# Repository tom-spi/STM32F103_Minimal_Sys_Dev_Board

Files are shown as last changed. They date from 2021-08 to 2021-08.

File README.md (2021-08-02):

# STM32F103_Minimal_Sys_Dev_Board

A minimal system STM32F103 based development board. All Major communication interfaces broken out. USB 2.0 device support. Complete with 3.3V regulator & 16MHz external crystal.
All I/O pins broken out onto headers & an SWD Header for programming. 
Boards manufactured and assembled by JLCPCB.

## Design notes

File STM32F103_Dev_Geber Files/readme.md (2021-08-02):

Gerber & drill files used for PCB manufacture.

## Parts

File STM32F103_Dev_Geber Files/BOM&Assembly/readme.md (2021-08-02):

BOM & position file for assembly. (In JLCPCB format)

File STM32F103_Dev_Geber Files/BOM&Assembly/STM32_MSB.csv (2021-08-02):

Comment | Designator | Footprint | LCSC
4u7 | C1,C3 | Capacitor_SMD:C_0603_1608Metric | C19666
1u | C2 | Capacitor_SMD:C_0603_1608Metric | C15849
100n | C4,C5,C6,C7 | Capacitor_SMD:C_0603_1608Metric | C14663
12p | C8,C9 | Capacitor_SMD:C_0603_1608Metric | C38523
3v3 | D1 | Capacitor_SMD:C_0805_2012Metric | C2297
USB_B_Micro | J1 | Connector_USB:USB_Mini-B_Wuerth_65100516121_Horizontal | C91144
I/O1 | J2 | Connector_PinHeader_2.54mm:PinHeader_2x07_P2.54mm_Vertical
I/O2 | J3 | Connector_PinHeader_2.54mm:PinHeader_2x07_P2.54mm_Vertical
CAN | J4 | Connector_PinHeader_2.54mm:PinHeader_1x02_P2.54mm_Vertical
I2C | J5 | Connector_PinHeader_2.54mm:PinHeader_1x02_P2.54mm_Vertical
USART | J6 | Connector_PinHeader_2.54mm:PinHeader_1x02_P2.54mm_Vertical
SWD | J7 | Connector_PinHeader_2.54mm:PinHeader_2x05_P2.54mm_Vertical
SPI | J8 | Connector_PinHeader_2.54mm:PinHeader_1x03_P2.54mm_Vertical
Jumper_NC_Small | JP1 | Connector_PinHeader_2.54mm:PinHeader_1x02_P2.54mm_Vertical
SolderJumper_2_Open | JP2 | Jumper:SolderJumper-2_P1.3mm_Open_RoundedPad1.0x1.5mm
1.5k | R1,R2 | Resistor_SMD:R_0603_1608Metric | C22843
10K | R3 | Resistor_SMD:R_0603_1608Metric | C25804
47 | R4 | Resistor_SMD:R_0603_1608Metric | C23182
4.7k | R5,R6 | Resistor_SMD:R_0603_1608Metric | C23162
MCP1825S | U1 | Package_TO_SOT_SMD:SOT-223-3_TabPin2
STM32F103C8Tx | U2 | Package_QFP:LQFP-48_7x7mm_P0.5mm | C8734
16MHz | Y1 | Crystal:Crystal_SMD_3225-4Pin_3.2x2.5mm | C13738

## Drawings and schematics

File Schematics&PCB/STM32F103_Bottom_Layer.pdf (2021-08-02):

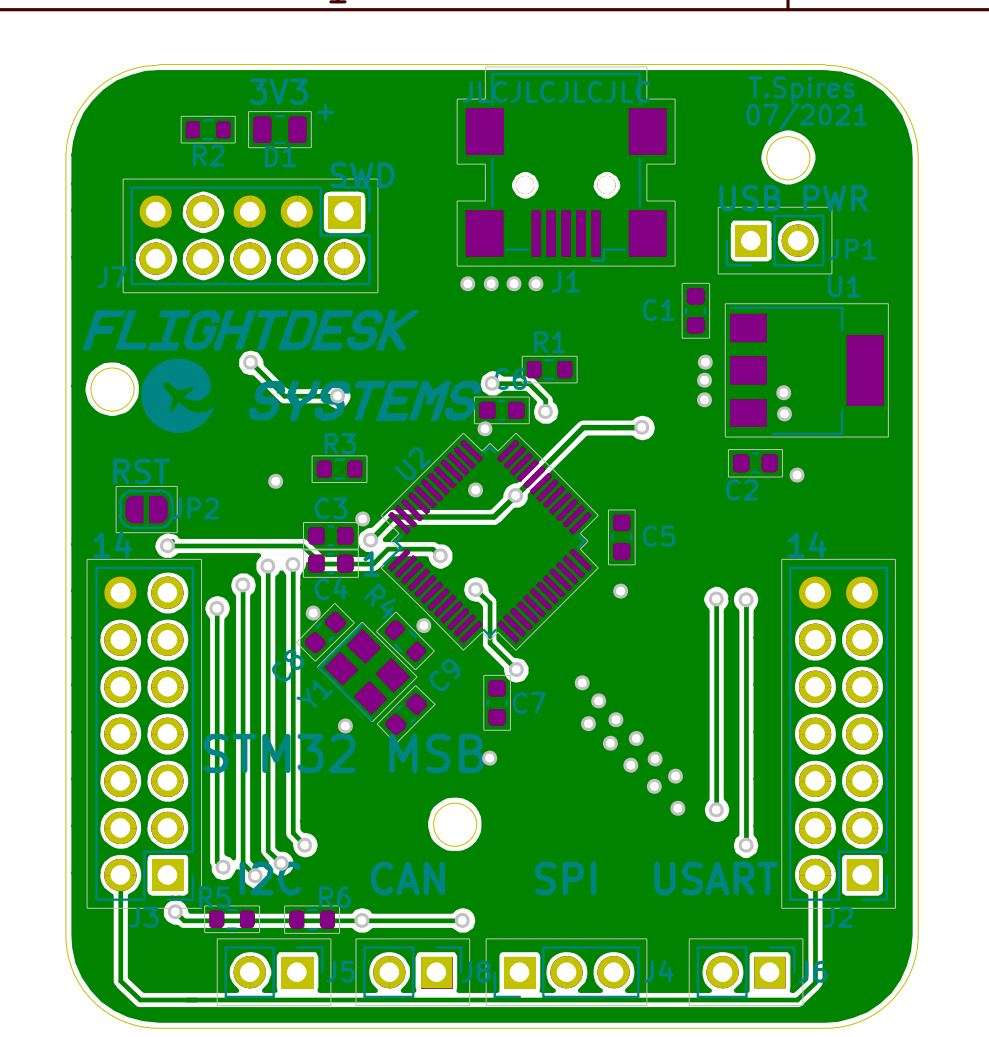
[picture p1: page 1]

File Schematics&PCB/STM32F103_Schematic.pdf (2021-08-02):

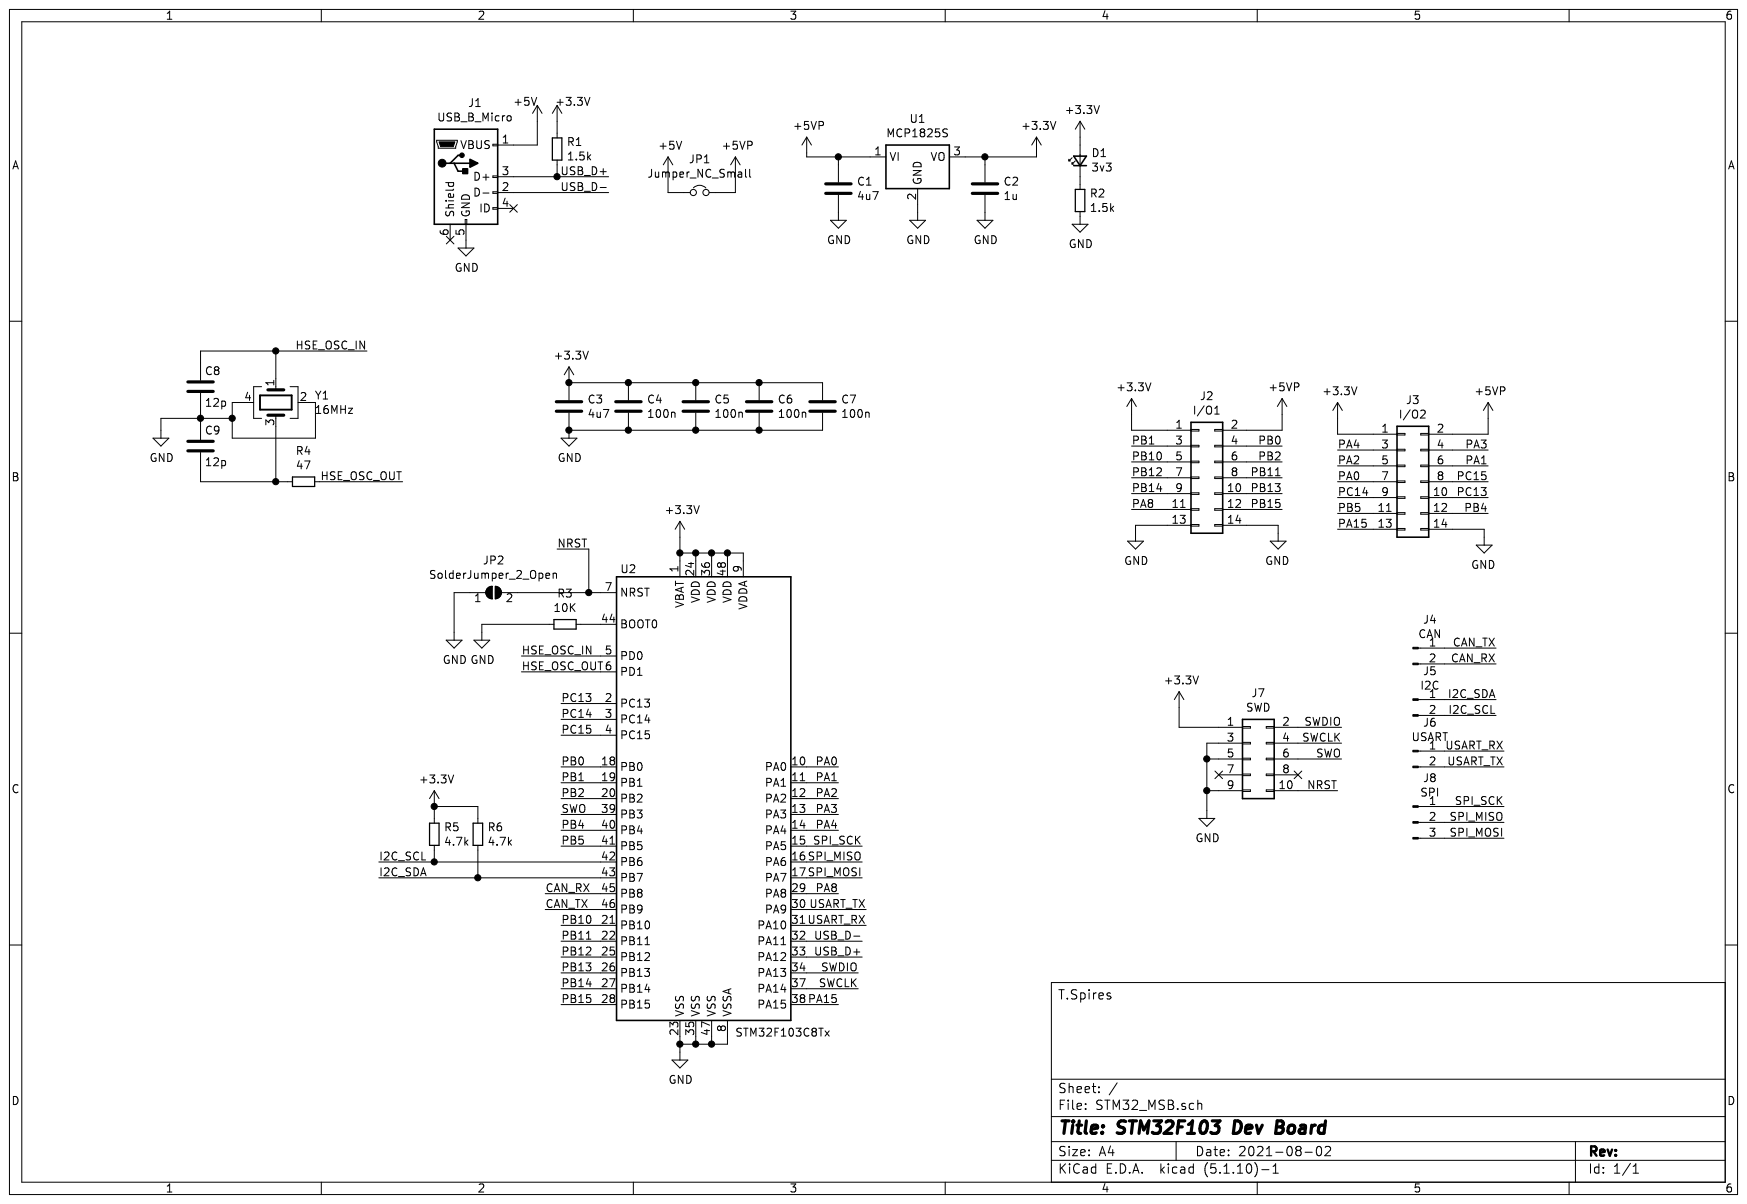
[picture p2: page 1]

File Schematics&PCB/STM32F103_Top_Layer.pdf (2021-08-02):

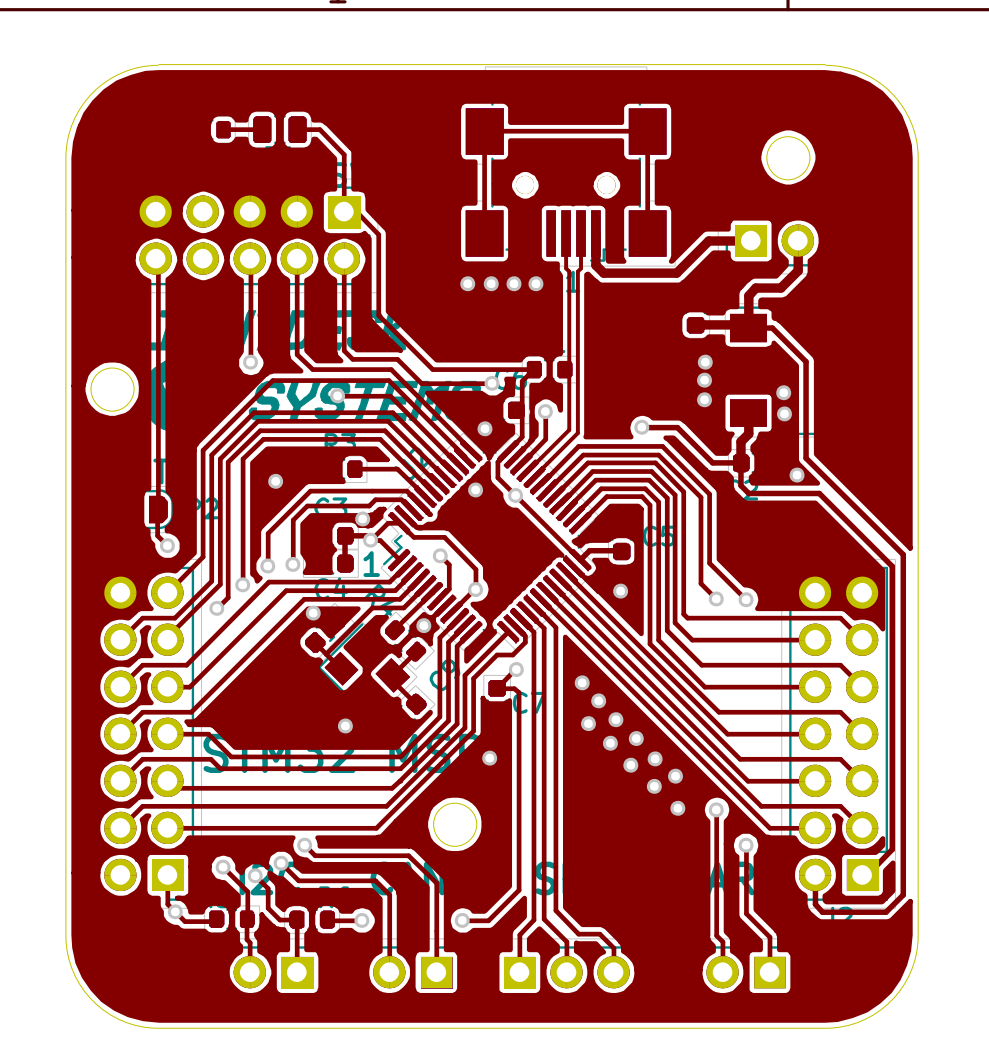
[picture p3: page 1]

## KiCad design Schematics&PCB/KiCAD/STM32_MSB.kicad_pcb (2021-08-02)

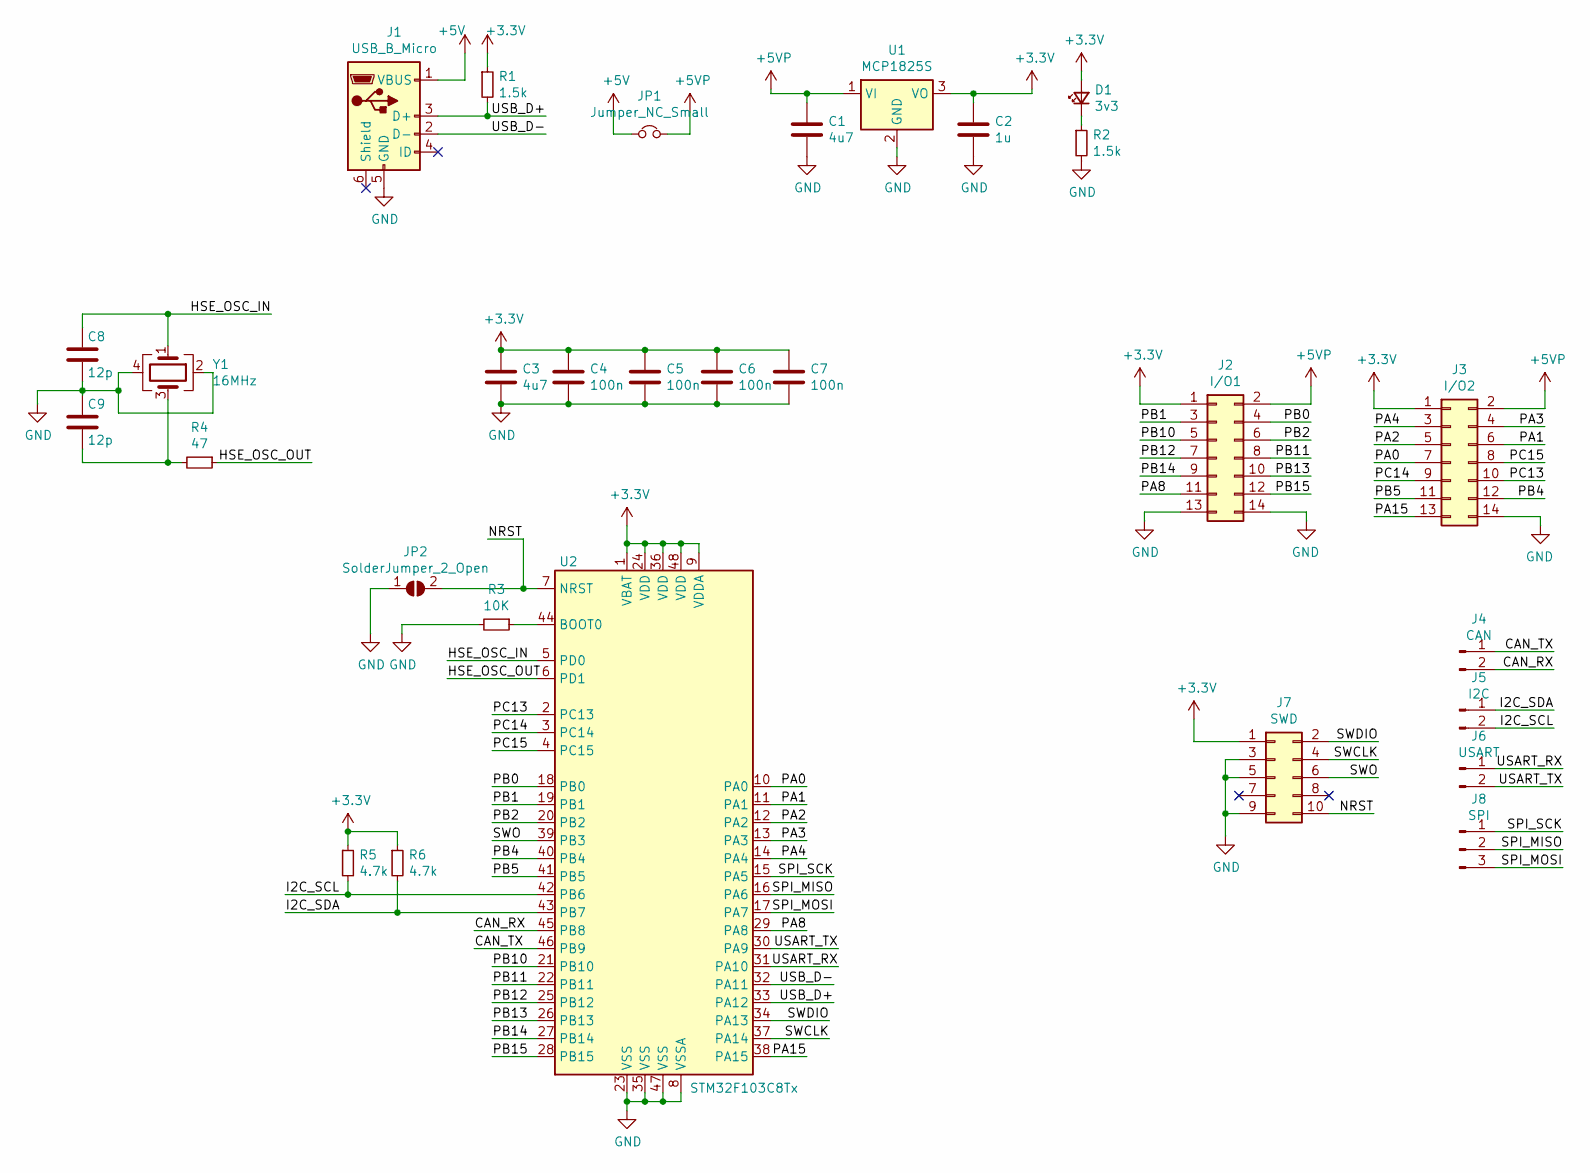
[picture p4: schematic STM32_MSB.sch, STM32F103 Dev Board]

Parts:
C1, C3: 4u7; C_0603_1608Metric; LCSC C19666
C2: 1u; C_0603_1608Metric; LCSC C15849
C4, C5, C6, C7: 100n; C_0603_1608Metric; LCSC C14663
C8, C9: 12p; C_0603_1608Metric; LCSC C38523
D1: 3v3; C_0805_2012Metric; LCSC C2297
J1: USB_B_Micro; USB_Mini-B_Wuerth_65100516121_Horizontal; LCSC C91144
J2: I/O1; PinHeader_2x07_P2.54mm_Vertical
J3: I/O2; PinHeader_2x07_P2.54mm_Vertical
J4: CAN; PinHeader_1x02_P2.54mm_Vertical
J5: I2C; PinHeader_1x02_P2.54mm_Vertical
J6: USART; PinHeader_1x02_P2.54mm_Vertical
J7: SWD; PinHeader_2x05_P2.54mm_Vertical
J8: SPI; PinHeader_1x03_P2.54mm_Vertical
JP1: Jumper_NC_Small; PinHeader_1x02_P2.54mm_Vertical
JP2: SolderJumper_2_Open; SolderJumper-2_P1.3mm_Open_RoundedPad1.0x1.5mm
R1, R2: 1.5k; R_0603_1608Metric; LCSC C22843
R3: 10K; R_0603_1608Metric; LCSC C25804
R4: 47; R_0603_1608Metric; LCSC C23182
R5, R6: 4.7k; R_0603_1608Metric; LCSC C23162
U1: MCP1825S; SOT-223-3_TabPin2
U2: STM32F103C8Tx; LQFP-48_7x7mm_P0.5mm; LCSC C8734
Y1: 16MHz; Crystal_SMD_3225-4Pin_3.2x2.5mm; LCSC C13738

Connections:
+3V3: C2.1, C3.1, C4.1, C5.1, C6.1, C7.1, D1.2 (A), J2.1, J3.1, J7.1, R1.1, R5.1, R6.1, U1.3 (VO), U2.1 (VBAT), U2.9 (VDDA), U2.24 (VDD), U2.36 (VDD), U2.48 (VDD)
+5V: J1.1 (VBUS), JP1.1
+5VP: C1.1, J2.2, J3.2, JP1.2, U1.1 (VI)
/CAN_RX: J4.2, U2.45 (PB8)
/CAN_TX: J4.1, U2.46 (PB9)
/HSE_OSC_IN: C8.1, U2.5 (PD0), Y1.1
/HSE_OSC_OUT: R4.1, U2.6 (PD1)
/I2C_SCL: J5.2, R5.2, U2.42 (PB6)
/I2C_SDA: J5.1, R6.2, U2.43 (PB7)
/NRST: J7.10, JP2.2 (B), U2.7 (NRST)
/PA0: J3.7, U2.10 (PA0)
/PA1: J3.6, U2.11 (PA1)
/PA2: J3.5, U2.12 (PA2)
/PA3: J3.4, U2.13 (PA3)
/PA4: J3.3, U2.14 (PA4)
/PA8: J2.11, U2.29 (PA8)
/PA15: J3.13, U2.38 (PA15)
/PB0: J2.4, U2.18 (PB0)
/PB1: J2.3, U2.19 (PB1)
/PB2: J2.6, U2.20 (PB2)
/PB4: J3.12, U2.40 (PB4)
/PB5: J3.11, U2.41 (PB5)
/PB10: J2.5, U2.21 (PB10)
/PB11: J2.8, U2.22 (PB11)
/PB12: J2.7, U2.25 (PB12)
/PB13: J2.10, U2.26 (PB13)
/PB14: J2.9, U2.27 (PB14)
/PB15: J2.12, U2.28 (PB15)
/PC13: J3.10, U2.2 (PC13)
/PC14: J3.9, U2.3 (PC14)
/PC15: J3.8, U2.4 (PC15)
/SPI_MISO: J8.2, U2.16 (PA6)
/SPI_MOSI: J8.3, U2.17 (PA7)
/SPI_SCK: J8.1, U2.15 (PA5)
/SWCLK: J7.4, U2.37 (PA14)
/SWDIO: J7.2, U2.34 (PA13)
/SWO: J7.6, U2.39 (PB3)
/USART_RX: J6.1, U2.31 (PA10)
/USART_TX: J6.2, U2.30 (PA9)
/USB_D+: J1.3 (D+), R1.2, U2.33 (PA12)
/USB_D-: J1.2 (D-), U2.32 (PA11)
GND: C1.2, C2.2, C3.2, C4.2, C5.2, C6.2, C7.2, C8.2, C9.1, J1.5 (GND), J2.13, J2.14, J3.14, J7.3, J7.5, J7.9, JP2.1 (A), R2.2, R3.2, U1.2 (GND), U2.8 (VSSA), U2.23 (VSS), U2.35 (VSS), U2.47 (VSS), Y1.2, Y1.4
unnamed: C9.2, R4.2, Y1.3
unnamed: D1.1 (K), R2.1
unnamed: R3.1, U2.44 (BOOT0)

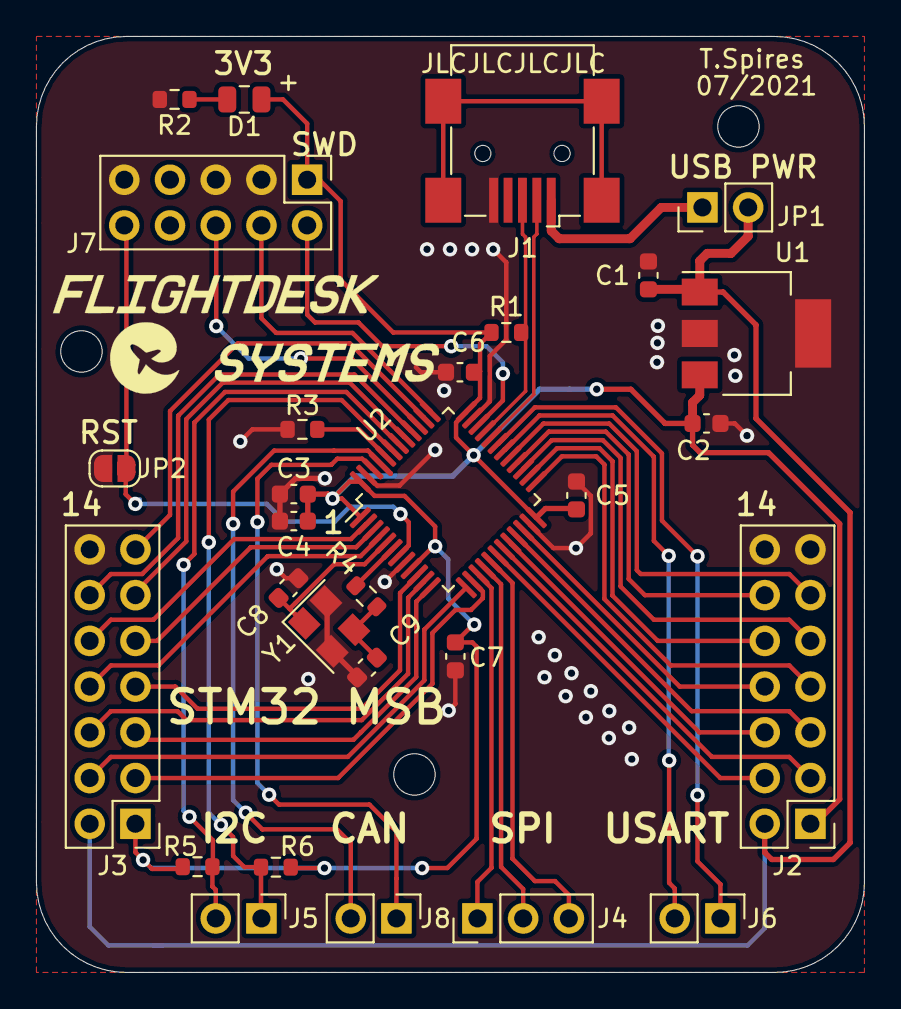
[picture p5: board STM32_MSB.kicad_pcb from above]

Board: 2 copper layers, 46.0 x 52.0 mm, 29 parts (0 on the bottom side), 45 nets.
